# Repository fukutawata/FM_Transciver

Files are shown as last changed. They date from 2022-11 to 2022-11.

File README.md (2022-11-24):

# FM_Transciver
very small fm transciver

# Built with
Kicad (ver. 6.0.9)
https://www.kicad.org

freerouting (ver.1.6.2)
https://github.com/freerouting/freerouting

supplier:JLCPCB
https://jlcpcb.com

# IC Parts
- BA1404(Datasheet: https://www.alldatasheet.jp/datasheet-pdf/pdf/35925/ROHM/BA1404.html)

- RTC6215S(Datasheet: http://aitendo3.sakura.ne.jp/aitendo_data/product_img/ic/radio/RTC6215/T-ST-6215N-DST-001-aitendo.pdf)
(This datasheet is RTC6215N. The internal structure of RTC6215N is the same as RTC6215N, but external structure is SSOP-16.(pitch:0.65mm)

# Overview
- overall schematic


- wiring diagram of the circuit


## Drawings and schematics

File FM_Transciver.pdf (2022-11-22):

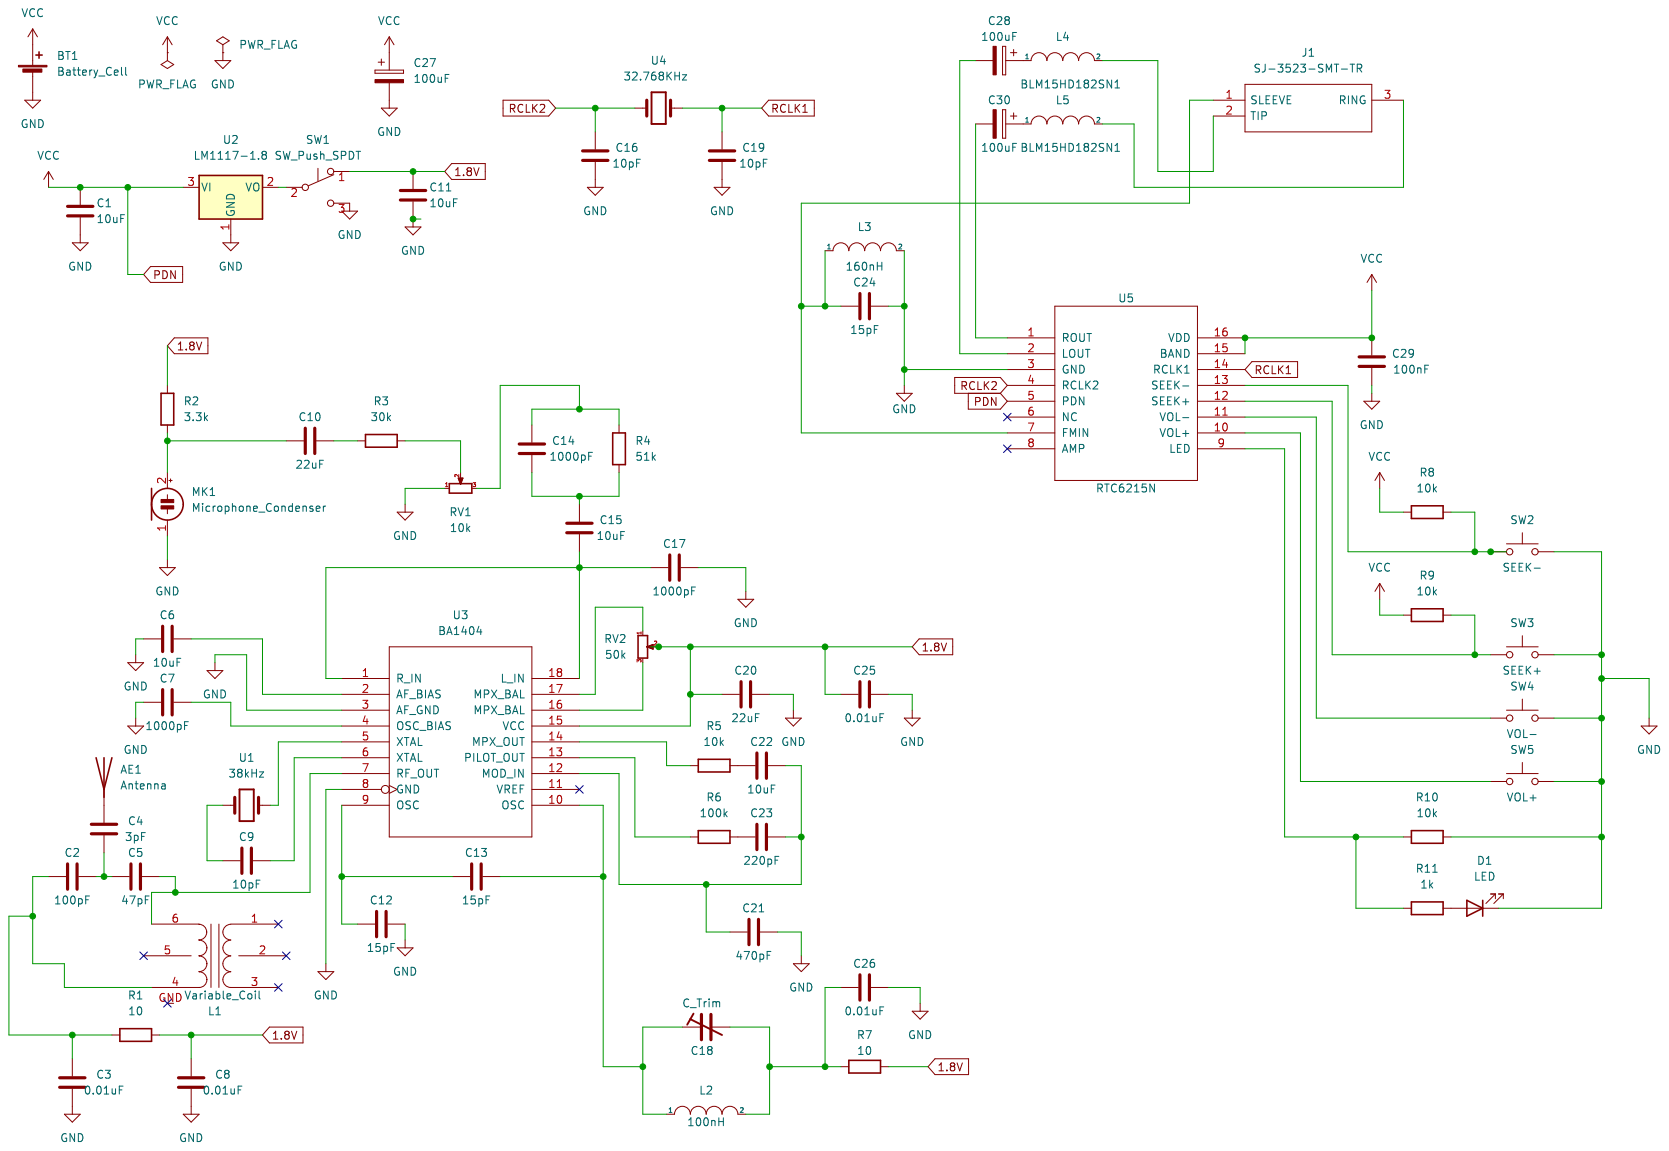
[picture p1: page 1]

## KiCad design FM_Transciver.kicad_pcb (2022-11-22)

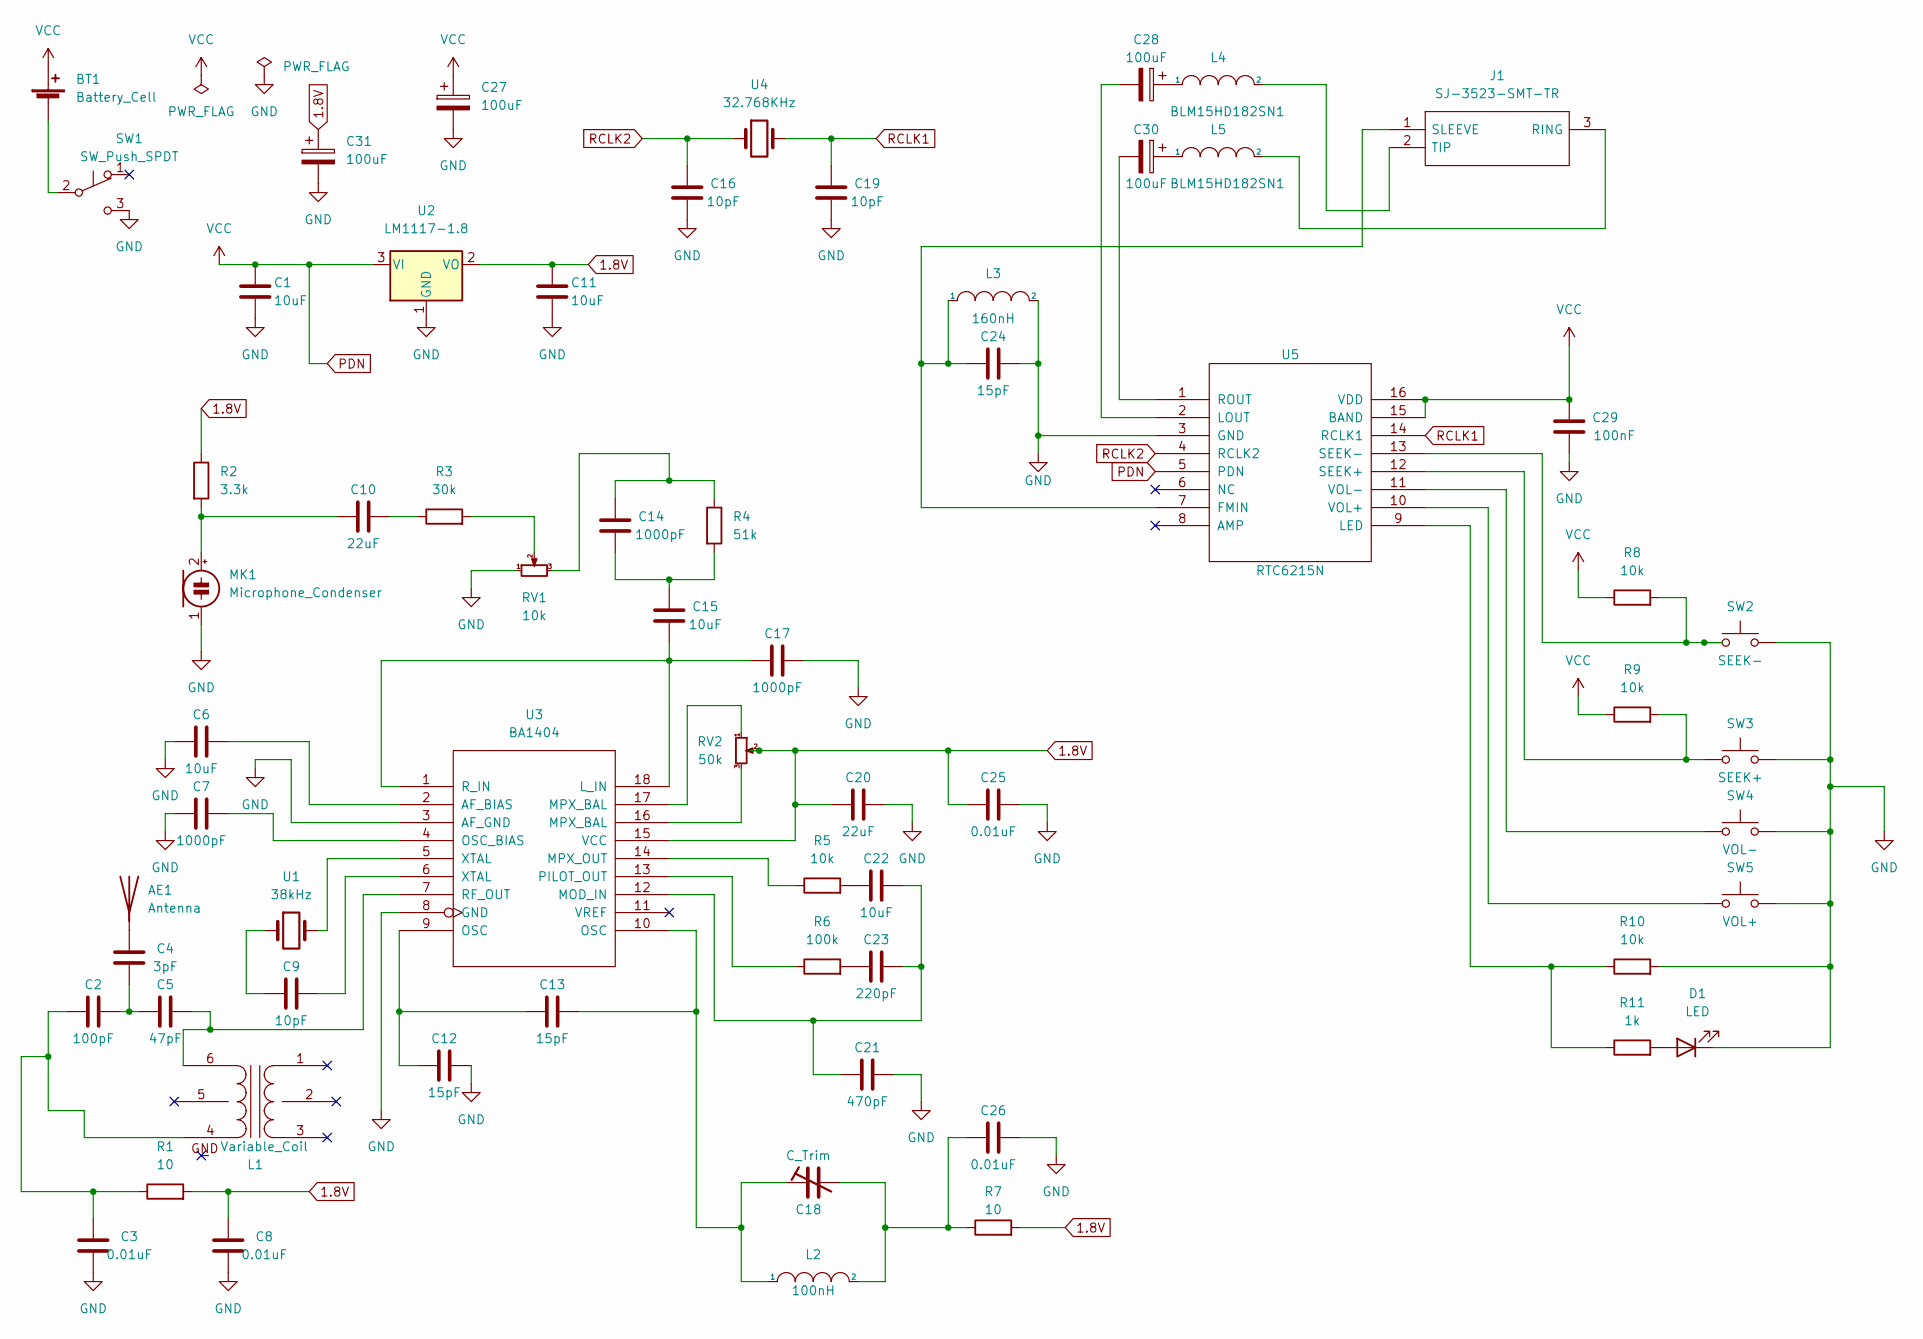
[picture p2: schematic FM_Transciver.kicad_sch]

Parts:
AE1: Antenna; PinSocket_1x01_P2.54mm_Vertical
BT1: Battery_Cell; PinSocket_1x02_P2.54mm_Vertical
C1, C6, C11, C15, C22: 10uF; C_0603_1608Metric_Pad1.08x0.95mm_HandSolder
C2: 100pF; C_0603_1608Metric_Pad1.08x0.95mm_HandSolder
C3, C8, C25, C26: 0.01uF; C_0603_1608Metric_Pad1.08x0.95mm_HandSolder
C4: 3pF; C_0603_1608Metric_Pad1.08x0.95mm_HandSolder
C5: 47pF; C_0603_1608Metric_Pad1.08x0.95mm_HandSolder
C7, C14, C17: 1000pF; C_0603_1608Metric_Pad1.08x0.95mm_HandSolder
C9, C16, C19: 10pF; C_0603_1608Metric_Pad1.08x0.95mm_HandSolder
C10, C20: 22uF; C_0603_1608Metric_Pad1.08x0.95mm_HandSolder
C12, C13, C24: 15pF; C_0603_1608Metric_Pad1.08x0.95mm_HandSolder
C18: C_Trim; Trimmer_Cap_TZ03
C21: 470pF; C_0603_1608Metric_Pad1.08x0.95mm_HandSolder
C23: 220pF; C_0603_1608Metric_Pad1.08x0.95mm_HandSolder
C27, C28, C30, C31: 100uF; CP_Radial_D5.0mm_P2.50mm
C29: 100nF; C_0603_1608Metric_Pad1.08x0.95mm_HandSolder
D1: LED; LED_0603_1608Metric_Pad1.05x0.95mm_HandSolder
J1: SJ-3523-SMT-TR; SJ3523SMTTR; Mouser Part Number 490-SJ-3523-SMT-TR
L1: Variable_Coil; VariableCoils-5CCEG
L2: 100nH; L_01005_0402Metric_Pad0.57x0.30mm_HandSolder
L3: 160nH; L_01005_0402Metric_Pad0.57x0.30mm_HandSolder
L4, L5: BLM15HD182SN1; L_01005_0402Metric_Pad0.57x0.30mm_HandSolder
MK1: Microphone_Condenser; CP_Radial_D5.0mm_P2.50mm
R1, R7: 10; R_0603_1608Metric_Pad0.98x0.95mm_HandSolder
R2: 3.3k; R_0603_1608Metric_Pad0.98x0.95mm_HandSolder
R3: 30k; R_0603_1608Metric_Pad0.98x0.95mm_HandSolder
R4: 51k; R_0603_1608Metric_Pad0.98x0.95mm_HandSolder
R5, R8, R9, R10: 10k; R_0603_1608Metric_Pad0.98x0.95mm_HandSolder
R6: 100k; R_0603_1608Metric_Pad0.98x0.95mm_HandSolder
R11: 1k; R_0603_1608Metric_Pad0.98x0.95mm_HandSolder
RV1: 10k; VariableResister
RV2: 50k; VariableResister
SW1: SW_Push_SPDT; slideSwitch1
SW2: SEEK-; tactswitch1
SW3: SEEK+; tactswitch1
SW4: VOL-; tactswitch1
SW5: VOL+; tactswitch1
U1: 38kHz; Crystal_Round_D2.0mm_Vertical
U2: LM1117-1.8; SOT-223-3_TabPin2
U3: BA1404; DIP-18_W7.62mm
U4: 32.768KHz; Crystal_SMD_3215-2Pin_3.2x1.5mm
U5: RTC6215N; RTC6215S

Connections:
1.8V: C8.1, C11.1, C20.2, C25.2, C31.1, R1.2, R2.1, R7.2, RV2.2, U2.2 (VO), U3.15 (VCC)
GND: C1.2, C3.2, C6.2, C7.2, C8.2, C11.2, C12.1, C16.2, C17.1, C19.2, C20.1, C21.1, C24.1, C25.1, C26.1, C27.2, C29.2, C31.2, D1.1 (K), L3.2, MK1.1 (-), R10.2, RV1.1, SW1.3 (C), SW2.2, SW3.2, SW4.2, SW5.2, U2.1 (GND), U3.3 (AF_GND), U3.8 (GND), U5.3 (GND)
unnamed: AE1.1 (A), C4.1
unnamed: BT1.2 (-), SW1.2 (B)
unnamed: C2.1, C4.2, C5.2
unnamed: C2.2, C3.1, L1.4 (SB), R1.1
unnamed: C5.1, L1.6 (SA), U3.7 (RF_OUT)
unnamed: C6.1, U3.2 (AF_BIAS)
unnamed: C7.1, U3.4 (OSC_BIAS)
unnamed: C9.1, U3.6 (XTAL)
unnamed: C9.2, U1.1
unnamed: C10.1, R3.1
unnamed: C10.2, MK1.2 (+), R2.2
unnamed: C12.2, C13.2, U3.9 (OSC)
unnamed: C13.1, C18.1, L2.1, U3.10 (OSC)
unnamed: C14.1, R4.1, RV1.3
unnamed: C14.2, C15.1, R4.2
unnamed: C15.2, C17.2, U3.1 (R_IN), U3.18 (L_IN)
unnamed: C18.2, C26.2, L2.2, R7.1
unnamed: C21.2, C22.1, C23.1, U3.12 (MOD_IN)
unnamed: C22.2, R5.2
unnamed: C23.2, R6.2
unnamed: C24.2, J1.1 (SLEEVE), L3.1, U5.7 (FMIN)
unnamed: C28.1, L4.1
unnamed: C28.2, U5.2 (LOUT)
unnamed: C30.1, L5.1
unnamed: C30.2, U5.1 (ROUT)
unnamed: D1.2 (A), R11.2
unnamed: J1.2 (TIP), L4.2
unnamed: J1.3 (RING), L5.2
unnamed: R3.2, RV1.2
unnamed: R5.1, U3.14 (MPX_OUT)
unnamed: R6.1, U3.13 (PILOT_OUT)
unnamed: R8.2, SW2.1, U5.13 (SEEK-)
unnamed: R9.2, SW3.1, U5.12 (SEEK+)
unnamed: R10.1, R11.1, U5.9 (LED)
unnamed: RV2.1, U3.17 (MPX_BAL)
unnamed: RV2.3, U3.16 (MPX_BAL)
unnamed: SW4.1, U5.11 (VOL-)
unnamed: SW5.1, U5.10 (VOL+)
unnamed: U1.2, U3.5 (XTAL)
PDN: BT1.1 (+), C1.1, C27.1, C29.1, R8.1, R9.1, U2.3 (VI), U5.5 (PDN), U5.15 (BAND), U5.16 (VDD)
RCLK1: C19.1, U4.2, U5.14 (RCLK1)
RCLK2: C16.1, U4.1, U5.4 (RCLK2)

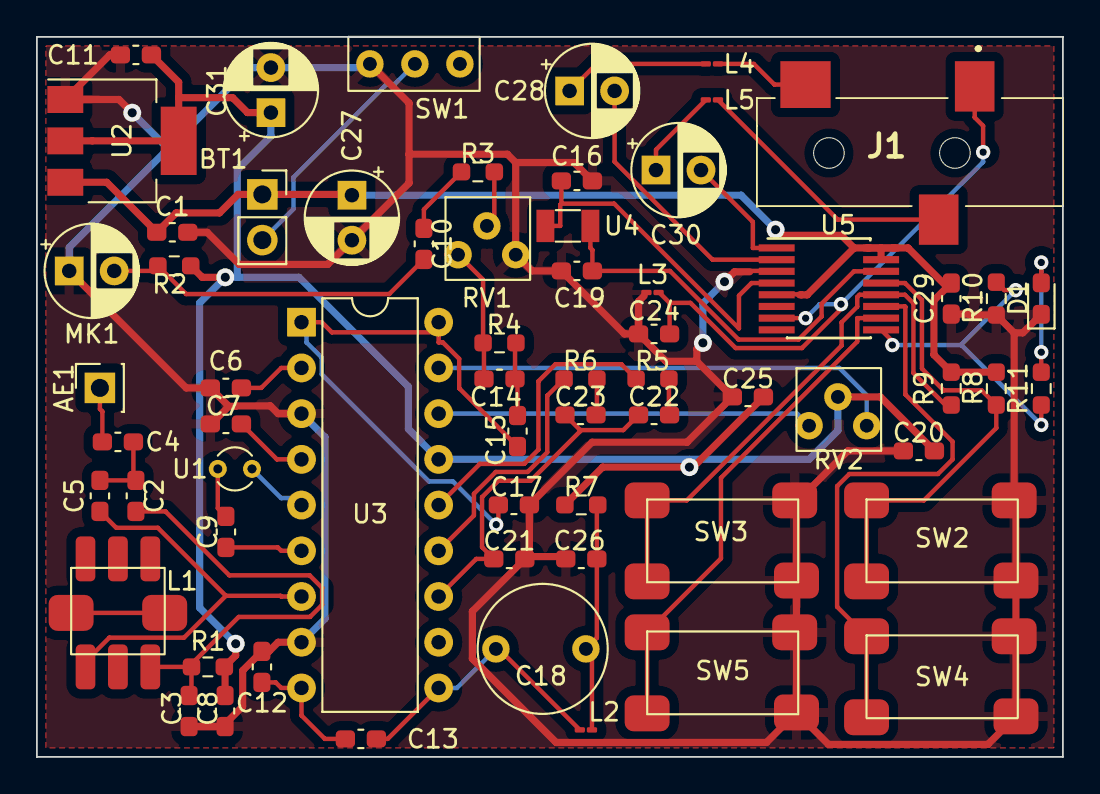
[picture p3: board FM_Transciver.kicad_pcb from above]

Board: 2 copper layers, 57.0 x 40.0 mm, 64 parts (0 on the bottom side), 44 nets.
